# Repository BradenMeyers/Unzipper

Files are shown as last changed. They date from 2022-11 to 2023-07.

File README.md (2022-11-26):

# Unzipper 

These are the code files for the unzipper project. 
We have built a pully retreival sytem for a zipline that can autonomously bring the pulley back to the top of the zipline after a rider has got off the line.
The code runs on the Arduino framework and the platformIO build platform. 
The ESP32 is the microcontroller we are using to support this project. The ESP32 runs the program and hosts a server that you can connect to via WIFI to adjust settings on the system. 
It is built into a custom designed circuit that we use to control the motors, lights, and sensors.

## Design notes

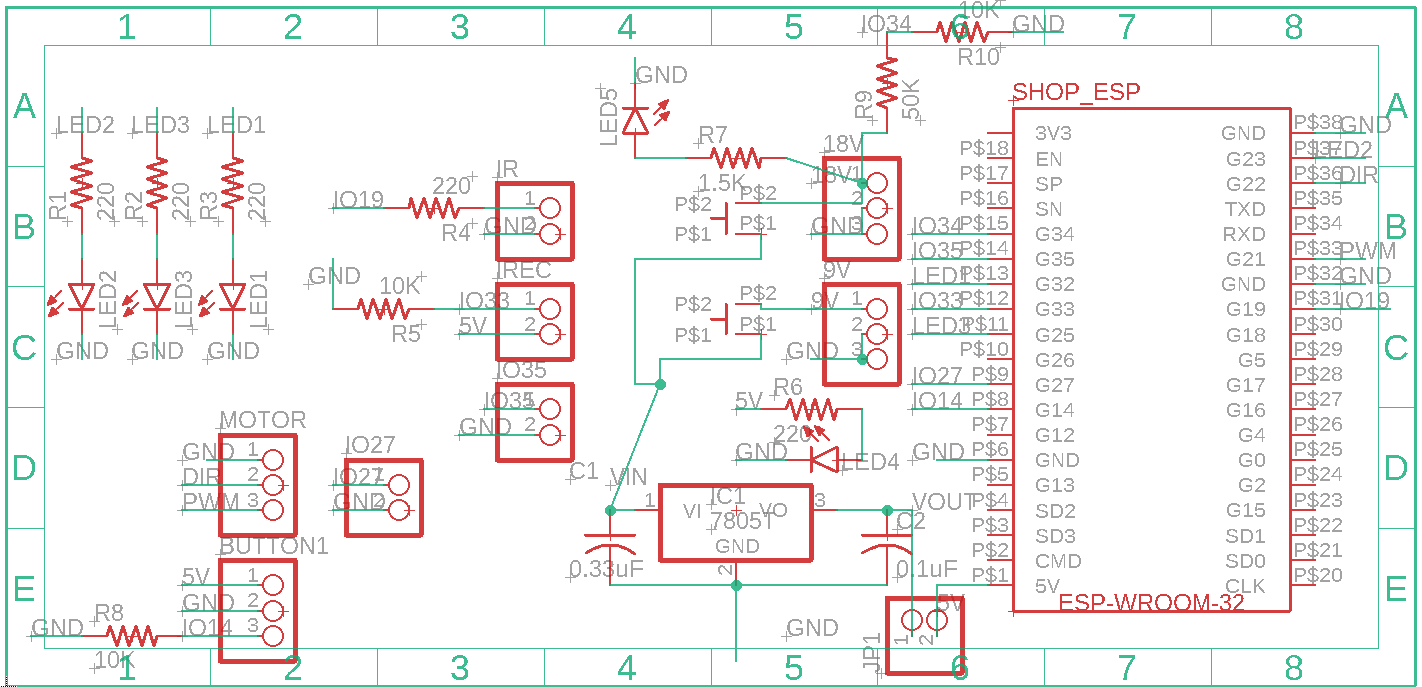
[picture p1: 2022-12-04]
NON CODE/PulleyProjectEagle/Schematic PulleyBoard.png

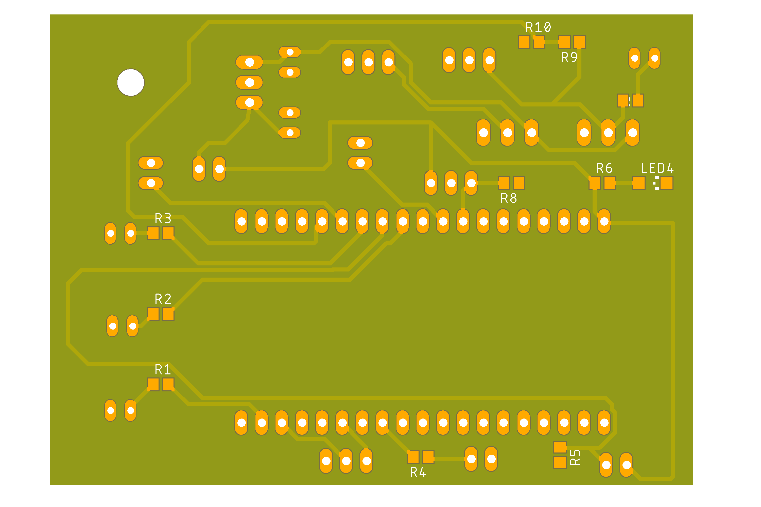
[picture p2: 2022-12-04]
NON CODE/PulleyProjectEagle/Pulleyboardv2back.png

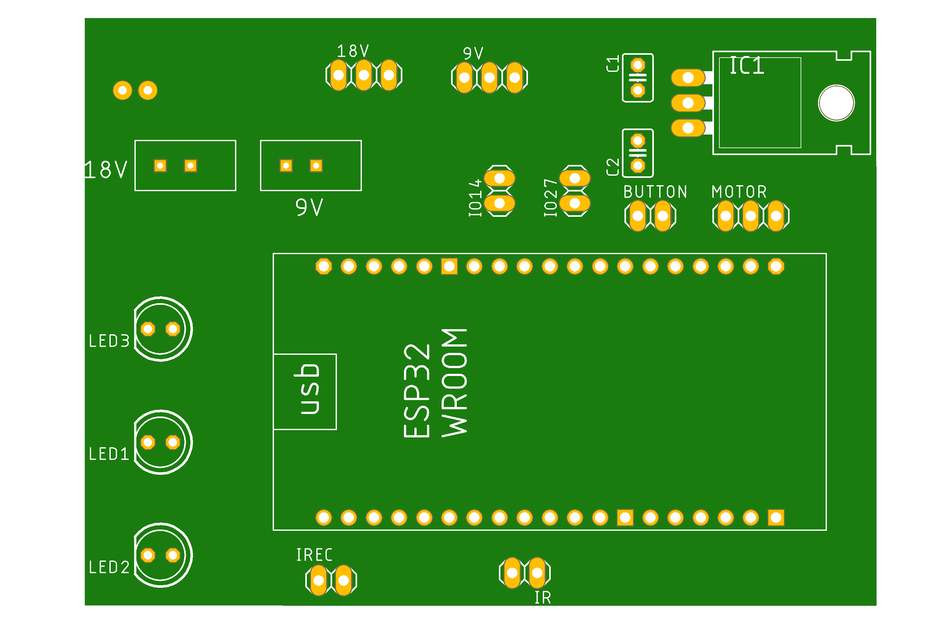
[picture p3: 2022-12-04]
NON CODE/PulleyProjectEagle/Pulleyboard.png

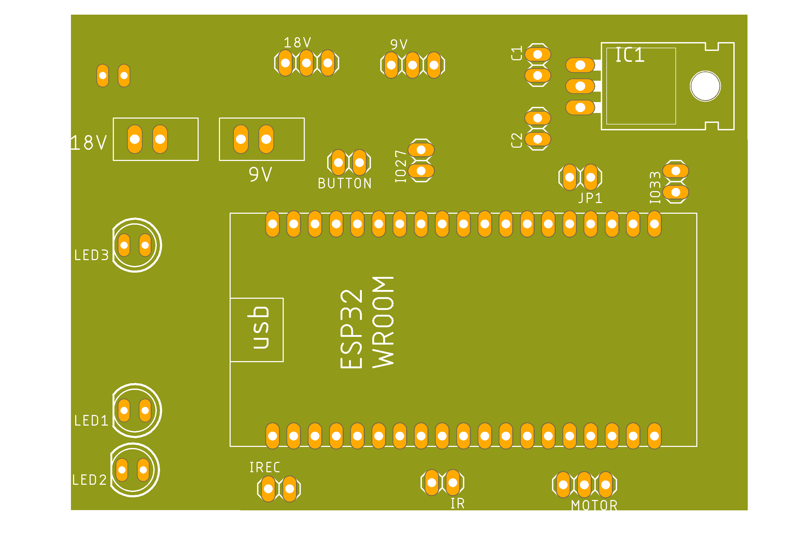
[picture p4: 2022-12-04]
NON CODE/PulleyProjectEagle/Pulleyboardv2.png

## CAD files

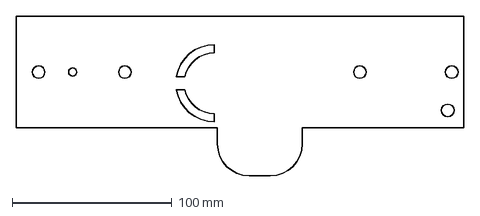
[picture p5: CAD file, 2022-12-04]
NON CODE/CAD files/DXF/Wall2Pulleyv2.DXF
280.0 x 100.0 mm

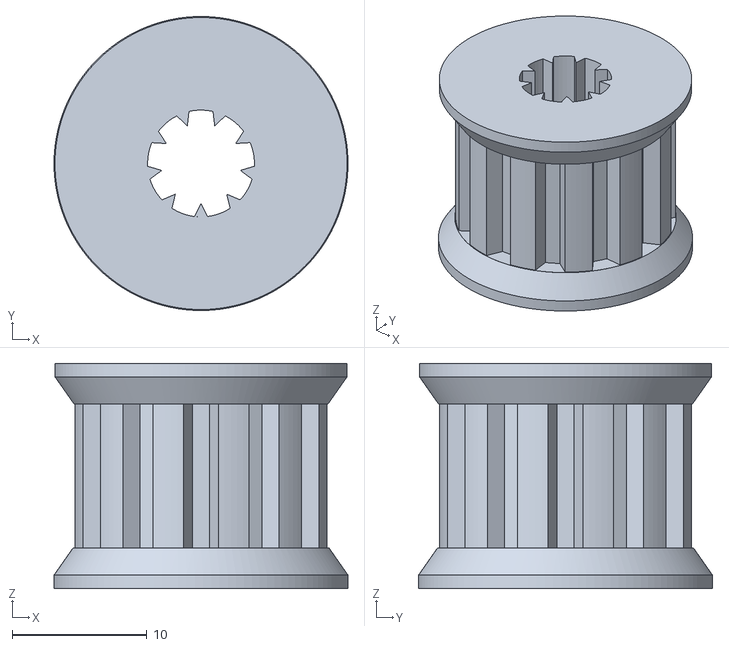
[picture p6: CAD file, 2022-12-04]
NON CODE/CAD files/STL/12T pulley v2.stl
21.8 x 21.8 x 16.7

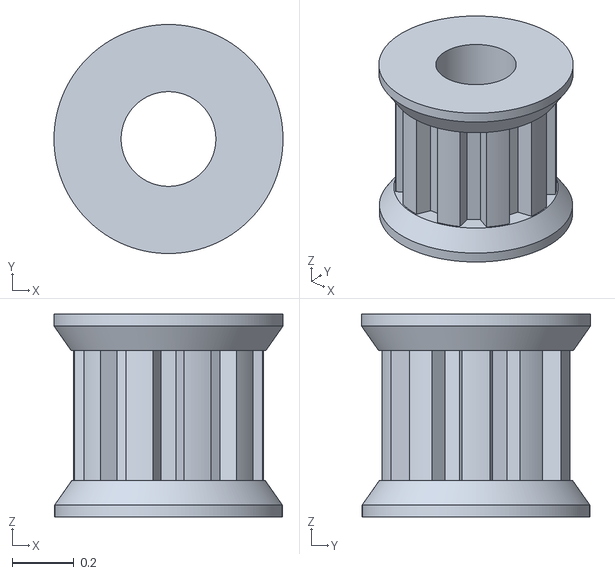
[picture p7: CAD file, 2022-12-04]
NON CODE/CAD files/code/Testing_esc/10T pulley v7.stl
0.743 x 0.743 x 0.658

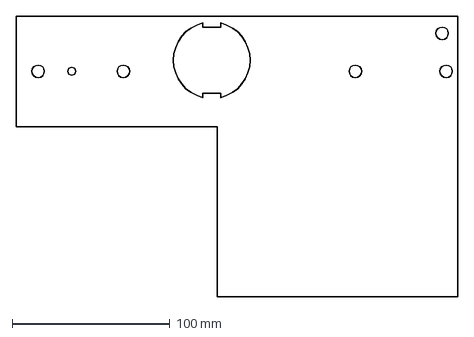
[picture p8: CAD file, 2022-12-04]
NON CODE/CAD files/DXF/Wall1Pulleyv2.DXF
280.0 x 178.0 mm

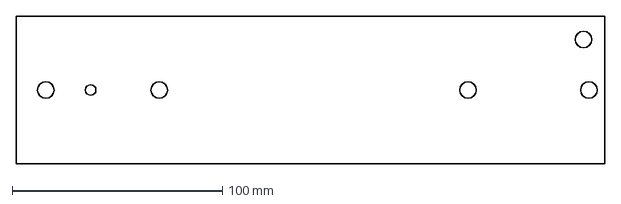
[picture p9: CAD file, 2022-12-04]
NON CODE/CAD files/DXF/Wall1Pulley.DXF
280.0 x 70.0 mm

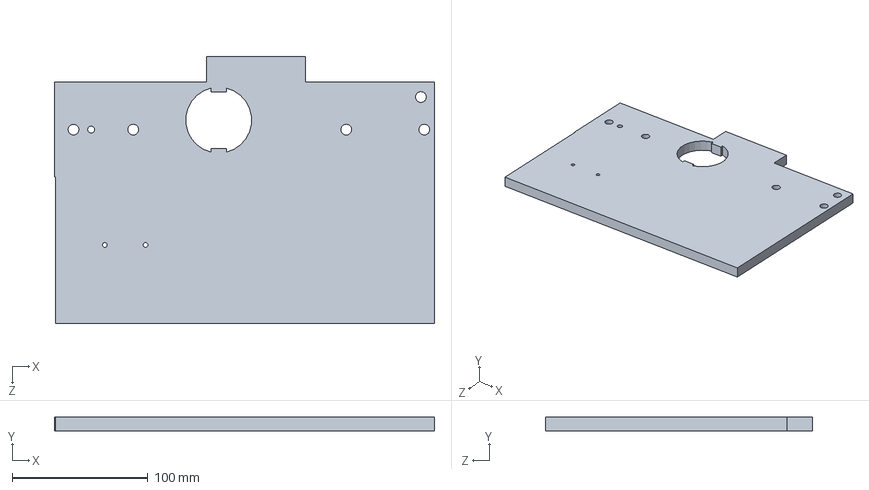
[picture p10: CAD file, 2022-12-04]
NON CODE/CAD files/ESPWall.SLDPRT
280.0 x 10.0 x 197.0 mm

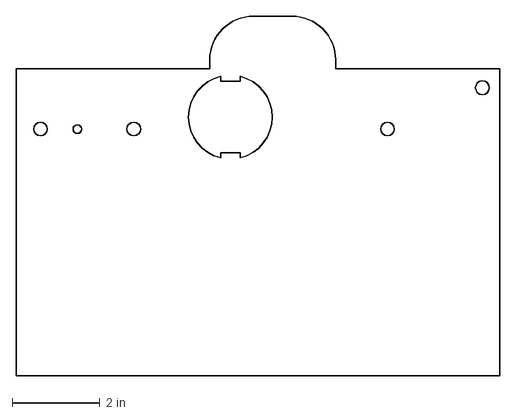
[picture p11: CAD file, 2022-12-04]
NON CODE/CAD files/Most recent/ESPWALLV3_STRONGER.DXF
11.0 x 8.21 in

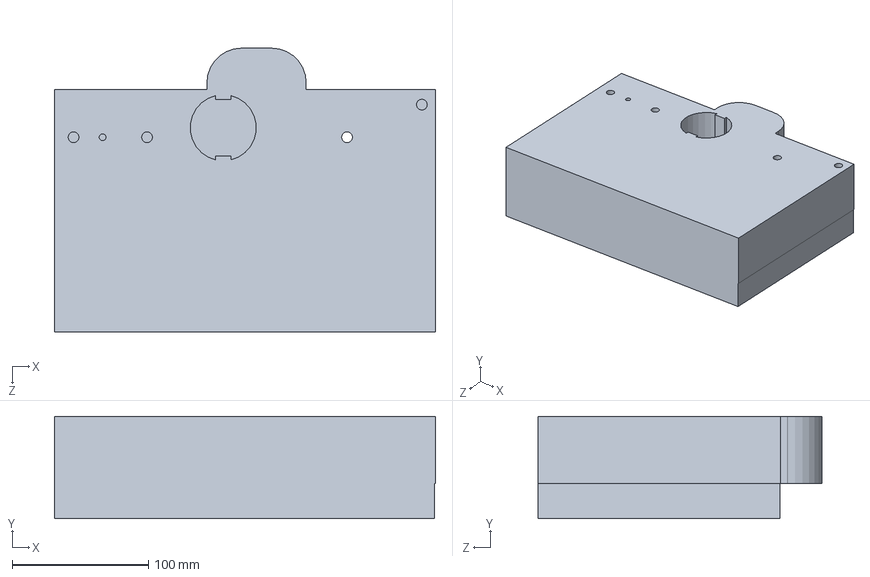
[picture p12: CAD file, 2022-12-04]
NON CODE/CAD files/Most recent/Remake for stupid head.SLDPRT
280.0 x 75.2 x 208.5 mm

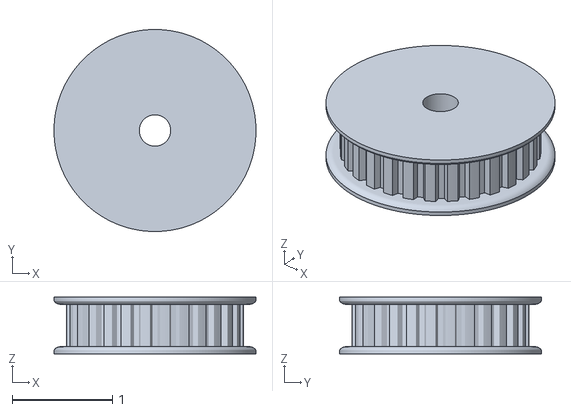
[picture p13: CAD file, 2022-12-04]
NON CODE/CAD files/STL/28TpulleyTrap.stl
2.01 x 2.01 x 0.563

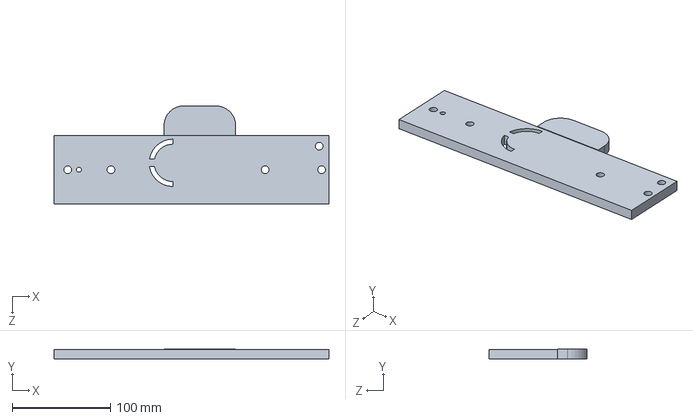
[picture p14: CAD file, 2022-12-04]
NON CODE/CAD files/Most recent/TensionWall.SLDPRT
280.0 x 10.5 x 100.0 mm

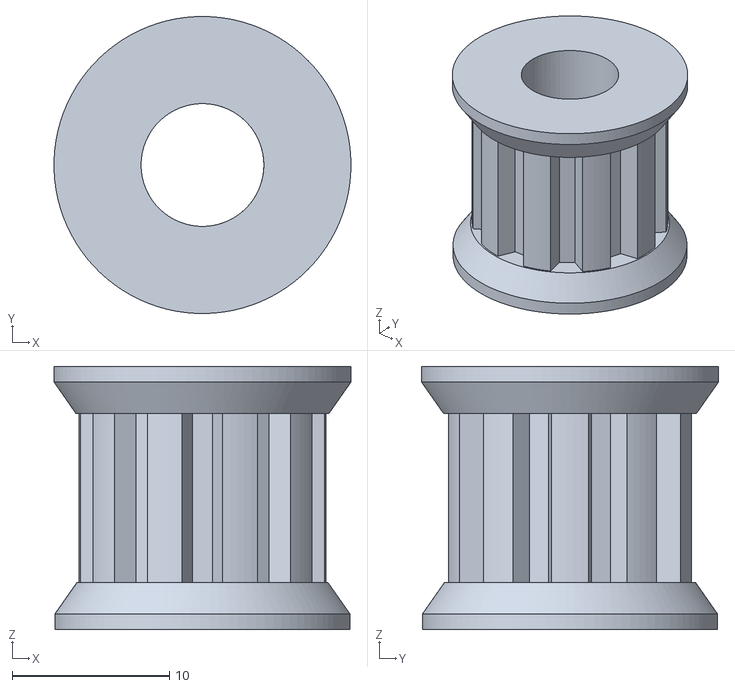
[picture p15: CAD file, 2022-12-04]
NON CODE/CAD files/STL/10T pulley v7.stl
18.9 x 18.9 x 16.7

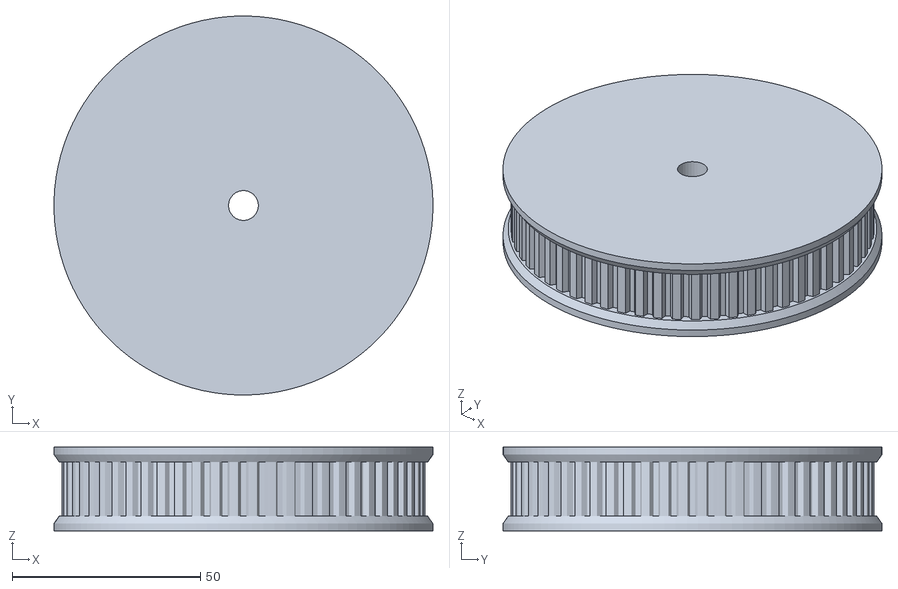
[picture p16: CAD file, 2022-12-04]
NON CODE/CAD files/STL/60T Pulley v1.stl
100.7 x 100.7 x 22.3

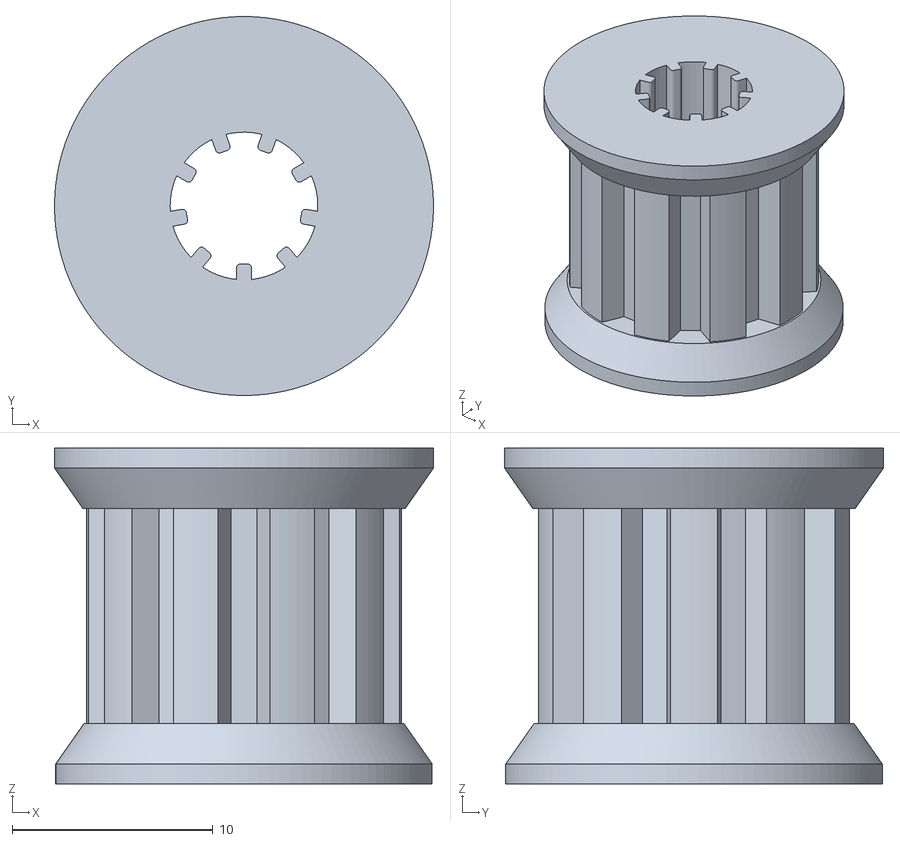
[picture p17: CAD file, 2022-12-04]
NON CODE/CAD files/STL/10T pulley v8_.stl
18.9 x 18.9 x 16.7

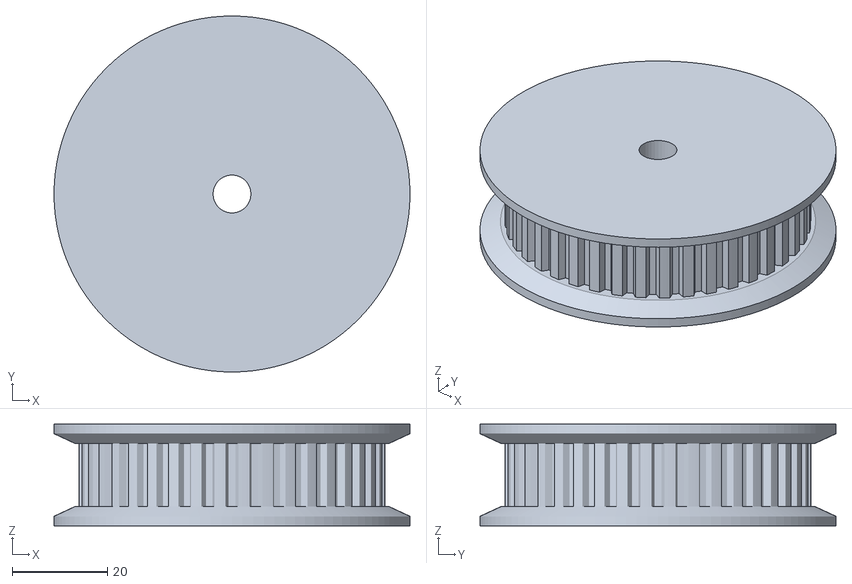
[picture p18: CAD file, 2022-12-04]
NON CODE/CAD files/STL/40T pulley v4.stl
74.6 x 74.6 x 21.3

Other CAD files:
NON CODE/CAD files/STL/10T pulley V2_oneTab.stl
NON CODE/CAD files/STL/48T Pulley v1.stl
NON CODE/CAD files/6495K711_TIMING BELT PULLEY.STEP
NON CODE/CAD files/6495K713_TIMING BELT PULLEY.STEP
NON CODE/CAD files/6495K723_TIMING BELT PULLEY.STEP
NON CODE/CAD files/6495K727_TIMING BELT PULLEY.STEP
NON CODE/CAD files/6495K731_TIMING BELT PULLEY.STEP
NON CODE/CAD files/6495K732_TIMING BELT PULLEY.STEP
NON CODE/CAD files/STL/10T pulley v5.stl
NON CODE/CAD files/STL/40T PulleyV1.stl
NON CODE/CAD files/code/Testing_esc/10T pulley v6.stl

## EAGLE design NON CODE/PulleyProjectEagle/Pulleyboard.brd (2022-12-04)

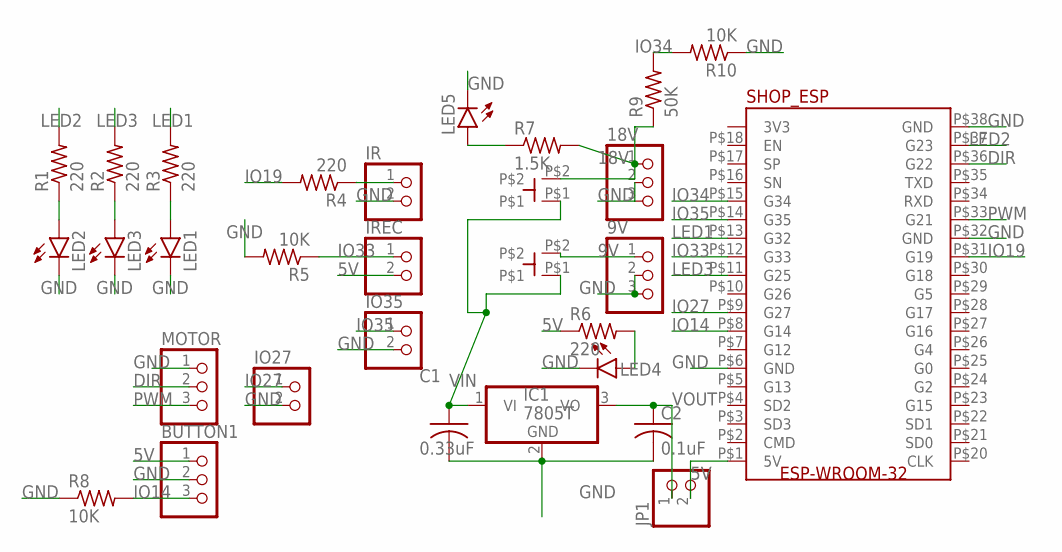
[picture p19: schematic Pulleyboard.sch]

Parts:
9V, 18V: PINHD-1X3; 1X03
9VSW, 18VSW: SWITCH; SWTICH
BUTTON1: PINHD-1X3; 1X03
C1: 0.33uF; C025-030X050
C2: 0.1uF; C025-030X050
IC1: 7805T; TO220H
IO27, IO35: PINHD-1X2; 1X02
IR: PINHD-1X2; 1X02
IREC: PINHD-1X2; 1X02
JP1: PINHD-1X2; 1X02
LED1, LED2, LED3, LED5: LED5MM
LED4: LEDCHIPLED_1206; CHIPLED_1206
MOTOR: PINHD-1X3; 1X03
R1, R2, R3, R4, R6: 220; R0805
R5, R8, R10: 10K; R0805
R7: 1.5K; R0805
R9: 50K; R0805
U$3: SHOP_ESP; ESP32-WROOM-32

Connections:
3V3: U$3.P$19 (3V3)
5V: BUTTON1.1, IREC.2, JP1.2, R6.1, U$3.P$1 (5V)
9V: 9V.1, 9VSW.P$2
18V: 18V.1, 18VSW.P$2, R7.2, R9.1
CMD: U$3.P$2 (CMD)
DIR: MOTOR.2, U$3.P$36 (G22)
GND: 9V.2, 9V.3, 18V.2, 18V.3, BUTTON1.2, C1.2, C2.2, IC1.2 (GND), IO27.2, IO35.2, IR.2, LED1.K (C), LED2.K (C), LED3.K (C), LED4.C, LED5.K (C), MOTOR.1, R5.2, R8.1, R10.1, U$3.P$6 (GND), U$3.P$32 (GND), U$3.P$38 (GND)
IO14: BUTTON1.3, R8.2, U$3.P$8 (G14)
IO19: R4.2, U$3.P$31 (G19)
IO27: IO27.1, U$3.P$9 (G27)
IO33: IREC.1, R5.1, U$3.P$12 (G33)
IO34: R9.2, R10.2, U$3.P$15 (G34)
IO35: IO35.1, U$3.P$14 (G35)
LED1: R3.2, U$3.P$13 (G32)
LED2: R1.2, U$3.P$37 (G23)
LED3: R2.2, U$3.P$11 (G25)
unnamed: LED2.A, R1.1
unnamed: LED3.A, R2.1
unnamed: LED1.A, R3.1
unnamed: LED5.A, R7.1
unnamed: IR.1, R4.1
unnamed: LED4.A, R6.2
PWM: MOTOR.3, U$3.P$33 (G21)
VIN: 9VSW.P$1, 18VSW.P$1, C1.1, IC1.1 (VI)
VOUT: C2.1, IC1.3 (VO), JP1.1

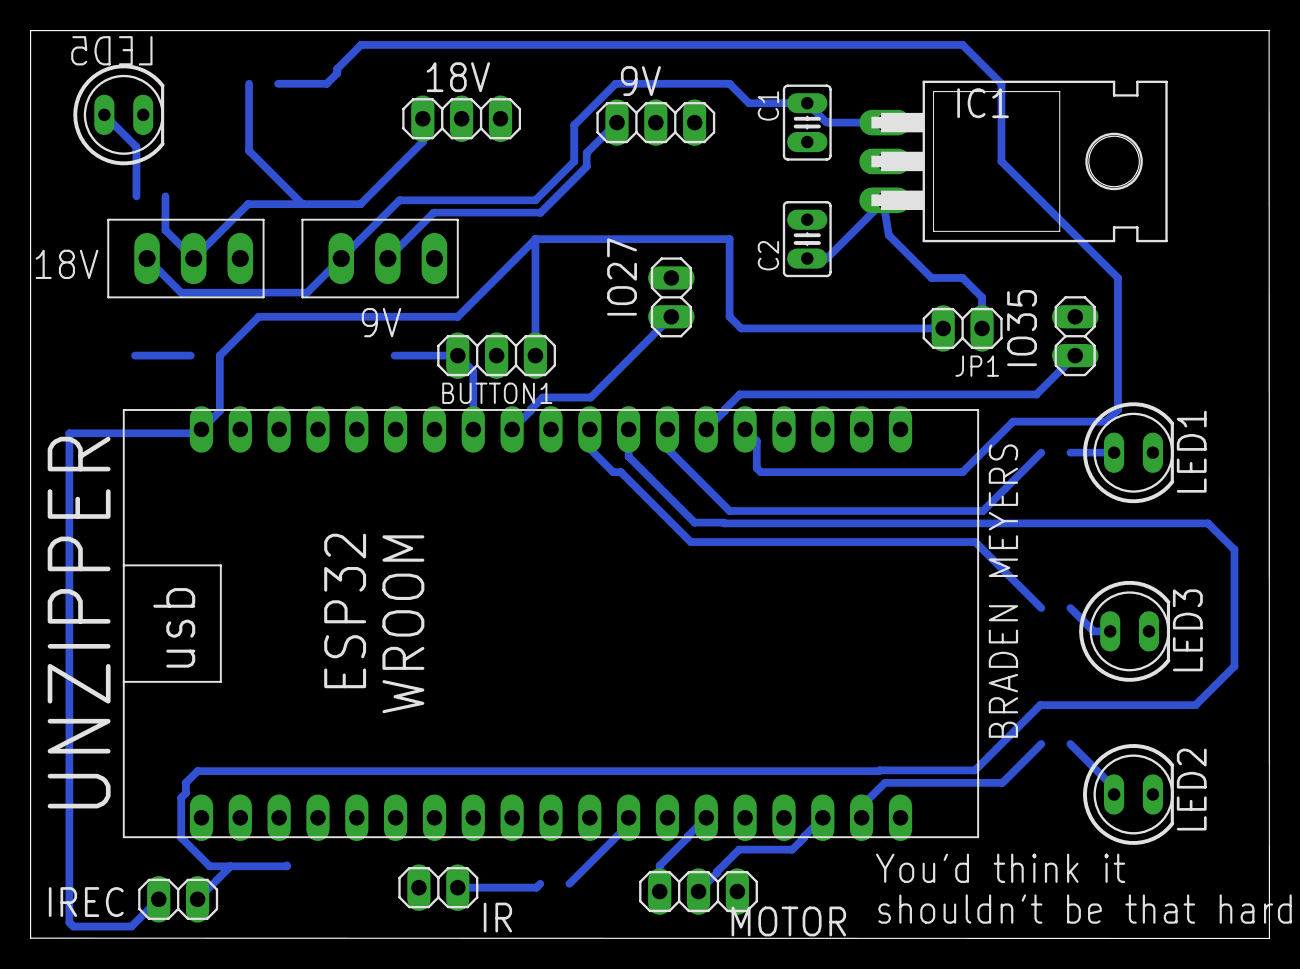
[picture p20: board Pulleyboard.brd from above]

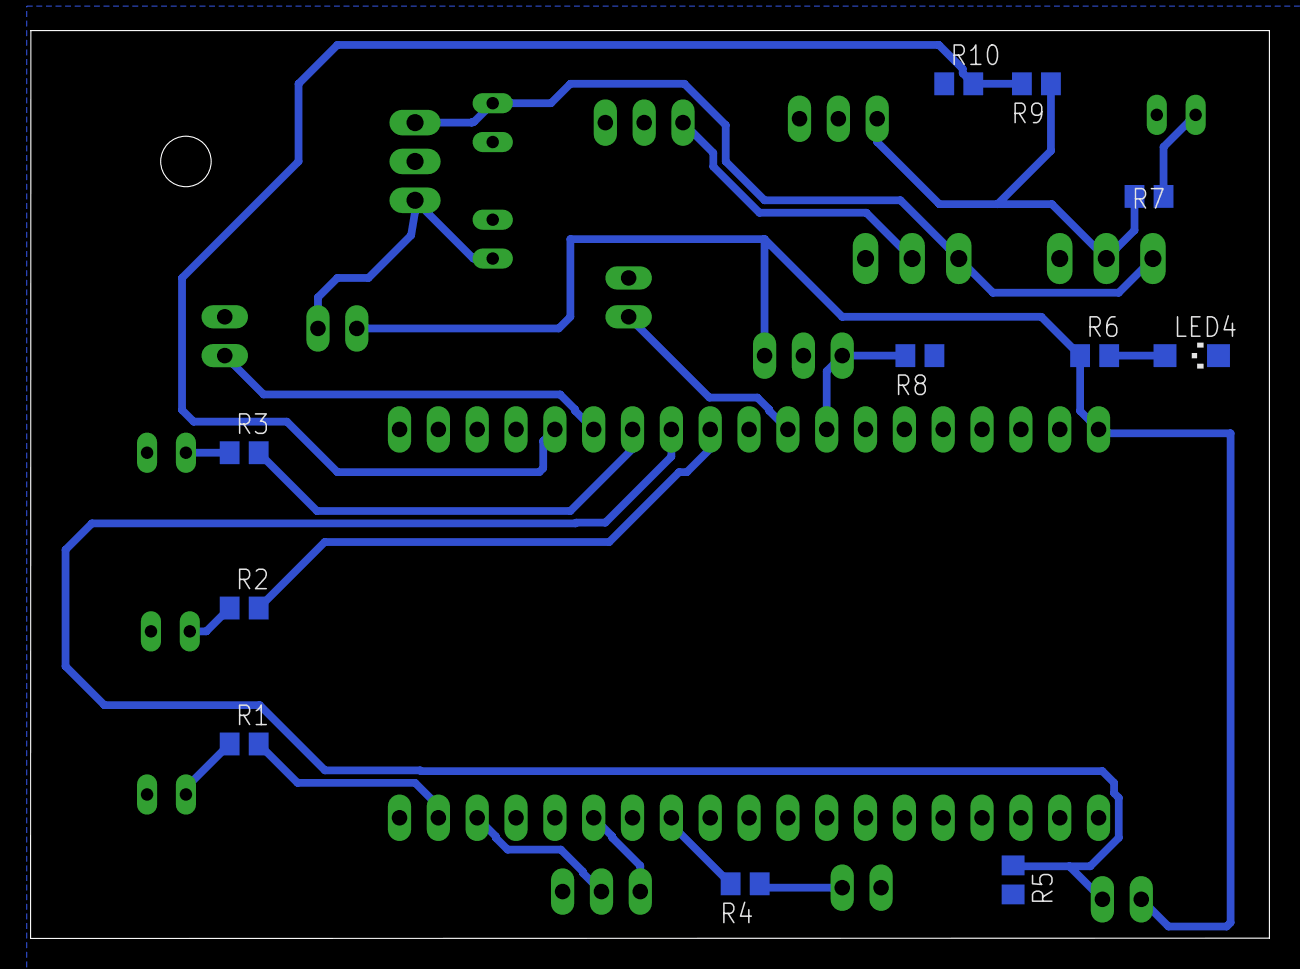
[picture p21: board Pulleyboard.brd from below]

Board: 2 copper layers, 81.0 x 59.4 mm, 30 parts (11 on the bottom side), 23 nets.

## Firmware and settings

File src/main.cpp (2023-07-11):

#include <Arduino.h>
#include <Wire.h>
#include <SPI.h>
#include <WiFi.h>
#include <AsyncTCP.h>
#include <ESPAsyncWebServer.h>
#include <remote.h>
#include <servoBrake.h>
#include <serverESP.h>
#include <accelerometer.h>
#include <timer.h>
#include <testCases.h>
#include <main.h>
#include <odometer.h>
#include <gps.h>
Timer recoveryTimer;
Timer atTheTopTimer;
Timer readyTimeOutTimer;
Timer handleBarTimer;

byte buzzer = 27;
byte motorDirection = 12;  //updated on mar 17
byte motor = 13;  //july5th updated becasue pin 26 on reset it was pulling high. 
byte handleBarSensor = 4;  //was 17 but switched cuz Serial on JULY 4th

#define motorChannel 1
#define resolution 8
#define freq 5000
#define RECOVERY_TO_READY_AFTER_BEEN_GRABBED_TIME 1700

static int motorAccelerationTimeLimit = 25;  //this determines how fast the motor increses its speed by one PWM value
const char* someoneOnLog = "Stopping motor because someone was on";
const char* wifiStopMotorLog = "Stopping motor because wifi";
const char* stalledLog = "Stopping motor because it is stalled";

void ledStateMachine(){
  static byte readyLight = 25;
  static byte zipLight = 32;
  static byte recoveryLight = 23;
  static bool initialized = false;
  if (!initialized) {
    initialized = true;
    pinMode(readyLight, OUTPUT);
    pinMode(zipLight, OUTPUT);
    pinMode(recoveryLight, OUTPUT);
  }
  switch(state){
    case READY:
      digitalWrite(readyLight, HIGH);
      digitalWrite(zipLight, LOW);
      digitalWrite(recoveryLight, LOW);
      break;
    case ZIPPING:
      digitalWrite(readyLight, LOW);
      digitalWrite(zipLight, HIGH);
      digitalWrite(recoveryLight, LOW);
      break; 
    case RECOVERY:
      digitalWrite(readyLight, LOW);
      digitalWrite(zipLight, LOW);
      digitalWrite(recoveryLight, HIGH);
      break;
    case TEST:
      digitalWrite(readyLight, LOW);
      digitalWrite(zipLight, HIGH);
      digitalWrite(recoveryLight, HIGH);
  }
}

void backgroundProcesses(){
  serverLoop();
  remoteLoop();
  loopGPS();
  // Serial.println("processing");
}

bool someoneOn(int timeLimit){
  backgroundProcesses();
  static byte handleBarSensorValue = 0;
  if(digitalRead(handleBarSensor) != handleBarSensorValue){
    if(handleBarTimer.getTime() > timeLimit){
      handleBarSensorValue = !handleBarSensorValue;
    }
  }
  else{handleBarTimer.start();}

  if(handleBarSensorValue){return true;}  //adjust handlebar to be opposite with the pullup
  return false;
}

void turnOnMotor(int speed){
  if(directionStr == "DOWN")
    digitalWrite(motorDirection, HIGH);
  else
    digitalWrite(motorDirection, LOW);
  ledcWrite(motorChannel, speed);
  /* if(batteryVoltage()< 16.50  && speed != 0){ 
    speed = speed + 10;
    mainlog.log("motor speed increase due to low battery voltage", true);
  } */
  if(speed == 0){
    //mainlog.log("MOTOR IS OFF------------------", true);
  }
}

void readyAtTheTop(){
  bool servoPositionLock = false;
  logger.checkLogLength();
  readyTimeOutTimer.start();
  writeServo(OFFPOS);
  while(!someoneOn(1000)){
    backgroundProcesses();
    //writeServo(OFFPOS);
    //writeServo(stopPosServo);      //Uncomment these lines out for the servo to be on during ready mode
    if(/* readyTimeOutTimer.getTime() > 120000 or */ wifiSkipToRecovery){
      state = RECOVERY;
      wifiSkipToRecovery = false;
      logger.log("Wireless command to Recovery", true);
      return;
    }
    while(racecarMode){
      writeServo(OFFPOS); //take break off 
      turnOnMotor(racecarSpeed);
      backgroundProcesses();
    }
    //writeServo(stopPosServo);  //uncomment this line when you turn servo on in ready mode
    turnOnMotor(0);
    if(beep == 1)
      digitalWrite(buzzer, HIGH);
    else
      digitalWrite(buzzer, LOW);
    if(state == TEST){
      return;
    }
  }
  //writeServo(OFFPOS);    //Uncomment these lines out for the servo to be on during ready mode
  delay(SERVODELAY);
  state = ZIPPING;
}

void movingDown(){
  startCount();
  while(someoneOn(1000)){
    loopOdometer();
    if(beep == 1)
      digitalWrite(buzzer, HIGH);
    else
      digitalWrite(buzzer, LOW);
    if(state == TEST){
      return;
    }
  }
  stopCount();
  state = RECOVERY;
  writeServo(stopPosServo);
  delay(SERVODELAY);
}

void stopTheMotor(){
  turnOnMotor(0);
  digitalWrite(buzzer, LOW);
  /* if(!wifiStopMotor){
    if(atTheTopTimer.getTime() > 2000){countToTopLimitOffset += 2;}
    else if(atTheTopTimer.getTime() < 1000){countToTopLimitOffset -= 2;}
  } */
  wifiStopMotor = false;
  recoveryTimer.start();
  while(recoveryTimer.getTime() < RECOVERY_TO_READY_AFTER_BEEN_GRABBED_TIME){}
  state = READY;
}

bool initialEscapeRecovery(){
  if(wifiStopMotor){
      wifiStopMotor = false;
      stopTheMotor();
      logger.log(wifiStopMotorLog, true);
      return true;
    }
  else if(someoneOn(500)){
      stopTheMotor();
      logger.log(someoneOnLog, true);
      return true;
  }
  else
    return false;
}

bool escapeRecovery(int motorSpeedparam){
  loopOdometer();  //does this need to be somewhere else? 
  if(someoneOn(50)){
      logger.log(someoneOnLog, true);
      return true;
    }
    if(wifiStopMotor){
      logger.log(wifiStopMotorLog, true);
      return true;
    }
    if((motorSpeedparam > (motorsMaxSpeed - 30)) and isStalled()){
      logger.log(stalledLog, true);
      return true;
    }
    if(!movingStable()){
      logger.log("System is unstable while moving", true);
      return true;
    }
  return false;
}

void moveToTop(){
  digitalWrite(buzzer, HIGH);
  //atTheTop = false;
  recoveryTimer.start();
  while(!checkStable(afterZipDelay*1000)){  //!checkStable(afterZipDelay*1000)  //recoveryTimer.getTime() < afterZipDelay*1000
    if(initialEscapeRecovery())
      return;
  }
  writeServo(OFFPOS); 
  delay(SERVODELAY*1.5);  
  logger.log("Begin speeding motor up", true);
  digitalWrite(buzzer, LOW);
  for(int motorSpeed=50; motorSpeed<=motorsMaxSpeed; motorSpeed++){
    turnOnMotor(motorSpeed);
    recoveryTimer.start();
    while(recoveryTimer.getTime() < motorAccelerationTimeLimit){
      if(escapeRecovery(motorSpeed)){
        stopTheMotor();
        return;
      }
    }
  }
  logger.log("Motor has reached max speed", true);
  while(true){
    //Serial.println(rotations);
    double distanceToEnd = getDistanceToEnd();
    if(half){
      turnOnMotor(motorsMaxSpeed/2);
      logger.log("half speed activated from remote", true);
    }
    else if(distanceToEnd < 15){
      turnOnMotor(motorsMaxSpeed/2);
    }
    if(escapeRecovery(motorsMaxSpeed)){
      break;
    }
    // if(isAtTheTop() and not atTheTop){
    //   turnOnMotor(motorsMaxSpeed - 70);
    //   logger.log("Turning motor down because were at the top", true);
    //   atTheTop = true;
    //   atTheTopTimer.start();
    // }
  }
  stopTheMotor();
}

void updateVariableStrings(){
  if(state == READY){stateStr = "Ready";}
  else if(state == ZIPPING){stateStr = "Zipping";}
  else if(state == RECOVERY){stateStr = "Recovery";}
  else if(state == RECOVERY){stateStr = "Test";}
  ledStateMachine();
}

void setup(){
  serverSetup();
  Serial.begin(112500);
  analogReadResolution(12);
  pinMode(handleBarSensor, INPUT_PULLUP);
  pinMode(buzzer, OUTPUT);
  pinMode(motorDirection, OUTPUT);
  pinMode(motor, OUTPUT);
  digitalWrite(motor, LOW);
  ledcSetup(motorChannel, freq, resolution);
  ledcAttachPin(motor, motorChannel);
  ledcWrite(motorChannel, 0);
  remoteSetup();
  setupAccel();
  servoSetup();
  setupOdometer();
  setupGPS();
  // Serial.println("i made it here");
}


void loop(){
  updateVariableStrings();
  logger.log("Current state : ", true);
  logger.log(stateStr);
  if(state == READY){readyAtTheTop();}
  else if(state == ZIPPING){movingDown();}
  else if(state == RECOVERY){moveToTop();}
  else if(state == TEST){testSelect();}
}

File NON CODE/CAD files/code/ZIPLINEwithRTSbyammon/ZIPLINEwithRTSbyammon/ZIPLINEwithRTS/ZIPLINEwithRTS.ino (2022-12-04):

//yayy
//this script could possibly be for the return to start function so the motor only turns on when that button is pressed. I dont know if this will work but I tried.
#define READY 1
#define ZIPPING 2              //don't know what this is for but seems important
#define RECOVERY 3
int motor = 9;
int handlebarbutton = 3;
int stopbutton = 10;        //changed the stop button to pin 10 instead of 11    
int stopbuttonvalue; 
int handlebarbuttonvalue;
int state = READY;
int readylight = 13;
int ziplight = 12;        // ziplight to 11
int recoverylight = 11;    //recoveryled to 12
unsigned long currenttime;
unsigned long aftertime;
unsigned long clocktime;
long finezip = 3000;

void starttime(){
  currenttime = millis();
}

void gettime(){
  aftertime = millis();
  clocktime = aftertime - currenttime;
}

void checkbuttons(){
  handlebarbuttonvalue = digitalRead(handlebarbutton);
  stopbuttonvalue = digitalRead(stopbutton);
}

void setup(){
  pinMode(motor, OUTPUT);
  pinMode(handlebarbutton, INPUT_PULLUP);
  pinMode(stopbutton, INPUT_PULLUP);
  pinMode(readylight, OUTPUT);
  pinMode(ziplight, OUTPUT);    //set the leds to output
  pinMode(recoverylight, OUTPUT); 
  Serial.begin(9600);
}


void loop(){
//------------------------------------------------------------------READY------------------------------------------------------------------------------------------------------------
  Serial.print("state = "), Serial.println(state);
  Serial.print("finezip is: "), Serial.println(finezip);
  if (state == READY){
    checkbuttons();
    digitalWrite(motor, LOW);
    digitalWrite(readylight, HIGH);
    while (handlebarbuttonvalue == 0){    // changed HBBV from 1 to 0
      handlebarbuttonvalue = digitalRead(handlebarbutton);
    }
    starttime();
    state = ZIPPING;
    digitalWrite(readylight, LOW);
    digitalWrite(ziplight, HIGH);           //turn on the zipping light
    delay(100);   //helps the button not go wack
  }



//-------------------------------------------------------------------ZIPPING-----------------------------------------------------------------------------------------------------------------------
  else if (state == ZIPPING){
    while (handlebarbuttonvalue == 1){        //changed HBBV from 0 to 1
      handlebarbuttonvalue = digitalRead(handlebarbutton);
    }
    gettime();
    Serial.print("time spent zipping: "), Serial.println(clocktime);

    while (handlebarbuttonvalue == 0){
      handlebarbuttonvalue = digitalRead(handlebarbutton);
    }
    while(handlebarbuttonvalue == 1){
      handlebarbuttonvalue = digitalRead(handlebarbutton);
    }
    delay(1000);
    state = RECOVERY;
  }
  
//--------------------------------------------------------------------RECOVERY--------------------------------------------------------------------------------------------------------
  else if (state == RECOVERY){         //Theres 3 stages to recovery, speed up the motor, go at full speed for a time (depending on how long they zipped), and finally go to half power untill its stopped.
    for (int i = 55; i <= 255; i++){     //this speeds up the motor slowly-------------- if want to start at a higher voltage then set i = larger num
      analogWrite(motor, i);
      delay(15);
      checkbuttons();
      if (stopbuttonvalue == 0 or handlebarbuttonvalue == 1){     //changed HBBV from 0 to 1
        break;
      }
    }
    
    starttime();
    clocktime = currenttime + clocktime + finezip;             //finezip will determine how long it goes at full speed and then switch to half speed
    currenttime = clocktime - currenttime;
    Serial.print("recovery time in normal: "), Serial.println(currenttime);
    Serial.print("recovery time in millis(): "), Serial.println(clocktime);
    Serial.println("full speed");
    
    while (stopbuttonvalue == 1 and handlebarbuttonvalue == 0 and currenttime < clocktime){     //changed HBBV from 1 to 0    
      checkbuttons();
      starttime();
      if (stopbuttonvalue == 0 or handlebarbuttonvalue == 1){     //changed HBBV from 0 to 1
        finezip = finezip - 500;
      }
    }
    
    analogWrite(motor, 155);      //put motor at half speed-----------------------------
    Serial.println("half speed");
    starttime();
    
    while(stopbuttonvalue == 1 and handlebarbuttonvalue == 0){    //changed HBBV from 1 to 0
      checkbuttons();
      if (stopbuttonvalue == 0 or handlebarbuttonvalue == 1){     //changed HBBV from 0 to 1
        gettime();
        Serial.print("half speed time: "), Serial.println(clocktime);
        if (clocktime > 4000){     //this is stating that if half speed has been going for to long then cut some time so it gets to half speed quicker
          finezip = finezip + 500;
        }
      }
    }
    
    digitalWrite(motor, LOW);             //stop motor
    Serial.println("motor is off");
    digitalWrite(recoverylight, LOW);      //turn the recoverylight off
    while (handlebarbuttonvalue == 1){
      handlebarbuttonvalue = digitalRead(handlebarbutton);
    }
    delay(300);
    state = READY;    
 }
}

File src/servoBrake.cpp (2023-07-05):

#include <Arduino.h>
#include <servoBrake.h>

#define MINMICRO 500
#define MAXMICRO 2500
#define NUETRALMICRO 1500       //PWM specs found on datasheet from part and on Amazon

#define SERVOPIN 19          //GPIO pin 4
#define SERVOCHANNEL 2
#define FREQUENCY 50    //AMAZON Specs for servo said frequency could be between 50-330hz
#define RESOLUTION 16   //found this on esp32 servo library as DEFAULT_TIMER_WIDTH

#define REFRESH_USEC 20000 //conversion for microseconds to ticks
#define DEFAULT_TIMER_WIDTH_TICKS 65536

int stopPosServo = 133;

bool attached = false;

void attachServo(int pin){
    ledcSetup(SERVOCHANNEL, FREQUENCY, RESOLUTION); // channel #, 50 Hz, timer width
    ledcAttachPin(SERVOPIN, SERVOCHANNEL);   // GPIO pin assigned to channel
    attached = true;
}

void detachServo()
{
    ledcDetachPin(SERVOPIN);
    attached = false;
}

void writeServo(int value)
{
    // treat values less than MIN_PULSE_WIDTH (500) as angles in degrees (valid values in microseconds are handled as microseconds)
    if (value < MINMICRO)
    {
        if (value < 0)
            value = 0;
        else if (value > 180)
            value = 180;

        value = map(value, 0, 180, MINMICRO, MAXMICRO);   //map an angle to microseconds
    }
    writeMicroseconds(value);
}

int usToTicks(int usec)
{
    return (int)((float)usec / ((float)REFRESH_USEC / (float)DEFAULT_TIMER_WIDTH_TICKS));   
}

void writeMicroseconds(int value){
    if (attached)   // ensure channel is valid
    {
        if (value < MINMICRO)          // ensure pulse width is valid
            value = MINMICRO;
        else if (value > MAXMICRO)
            value = MAXMICRO;

        value = usToTicks(value);  // convert to ticks
        // do the actual write
        ledcWrite(SERVOCHANNEL, value);
    }
}



int ticksToUs(int ticks)
{
    return (int)((float)ticks * ((float)REFRESH_USEC / (float)DEFAULT_TIMER_WIDTH_TICKS)); 
}

void servoSetup(){
    writeServo(OFFPOS);
    attachServo(SERVOPIN);
    writeServo(OFFPOS);
    Serial.println("Servo setup");
    delay(100);
}

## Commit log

2022-12-04 added cad files
    [10T pulley V2_oneTab.stl, 10T pulley v5.stl, 10T pulley v6.stl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]
2022-12-04 photos of cicruit board
2023-03-17 accelerometer with Stability
2023-03-19 Servo was breaking the motor
2023-05-08 added brake file
2023-05-08 unstable stop while moving and Servo Brake
    [accelerometer.cpp, main.cpp]
2023-05-09 updated brake
2023-05-15 Mostly working. Small bug in stable
    [accelerometer.cpp, main.cpp, remote.cpp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]
